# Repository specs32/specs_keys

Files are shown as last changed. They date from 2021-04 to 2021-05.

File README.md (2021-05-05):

# specs_keys - REV 1 (confirmed working, typing on it now :D)

### TKL ISO keyboard based on an g80-3000HAD running QMK

15 Years ago I found 2 g80-3000 HAD Keyboards in the trash, one broke lately so I designed a PCB to mount these sweet sweet Cherry MX black switches on it.

The base plate is the acryl plate from an old TFT Monitor cut to size and sanded. (roughly)
Between PCB and baseplate is some foamy stuff for dampening.

So, except the pcb and the mcu and a couple smd parts this thing is completly salvaged from trash.

Overall cost per board with parts (except switches) : 18 €

(8 € per PCB and 10 € for SMD parts, rest is salvaged, so this is probably the cheapest build out there)

Features  :
  - ATMega 32U4 @ 8 MHz (why the crystal ... such a waste, sigh)
  - USB-C jack **with FUSE and full ESD protection** (gnd vcc d+ d-)
  - MOSFET controlled bottom backlighting pads for 14 LEDs with resistors plus 2 extra 2mm connectors for lantern style lightning
  - Scroll and caps indicators (active low atm.. I kinda like it)
  - SPI interface and reset
  - 340mA overall power consumption with full lights (I put in UV / pink LEDs and 14 Ω Resistors)

the QMK layout and config can be found here :  https://github.com/specs32/specs_keys/tree/main/specskeys

I hex the MCU with avrdude from cli after QMK compile, somehow I had trouble with bootloaders all my life ^^ (also safer this way .. I guess;))

> qmk_firmware [master]× » avrdude -c usbasp -p m32u4 -B10 -U lfuse:w:0xD2:m -U hfuse:w:0x98:m -U efuse:w:0xFF:m

> qmk_firmware [master]× » avrdude -c usbasp -pm32u4 -B10 -Uflash:w:.build/specskeys_default.hex                

designed with kicad nightly Version: (5.99.0-10004-g132ec37b56), release build
and some gimp

credits :

- evyd13 and ebastler (to modify the g80-3003 design was my initial attempt but I did build the PCB from scratch then)
- the designers of evil80 (whoever that might be, couldn't find any infos on that) I used some of their qmk layout information as info for mine

License on the KiCAD Design files : ♥ CC-BY-SA-4.0

All other parts of this build inherit their Licenses from their origin.

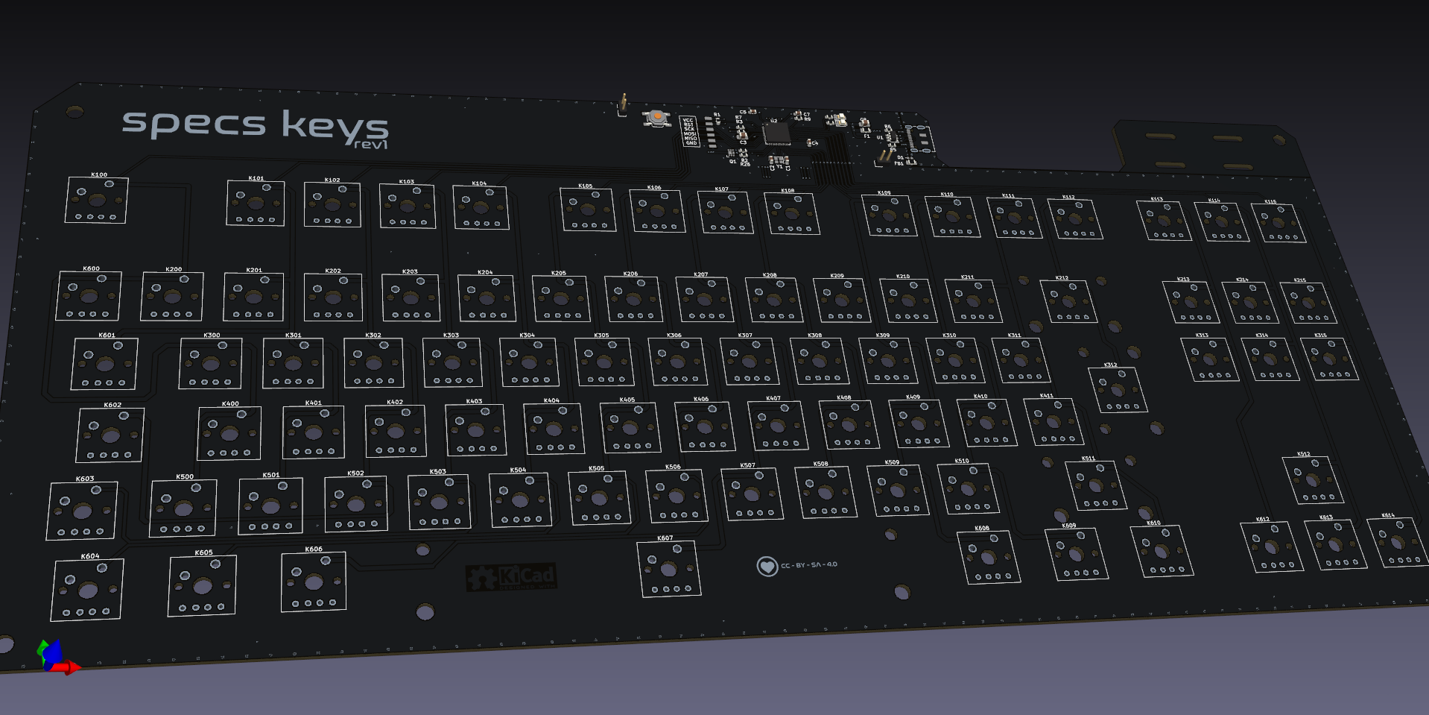
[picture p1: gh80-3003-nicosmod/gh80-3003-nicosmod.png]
3d-VIEW


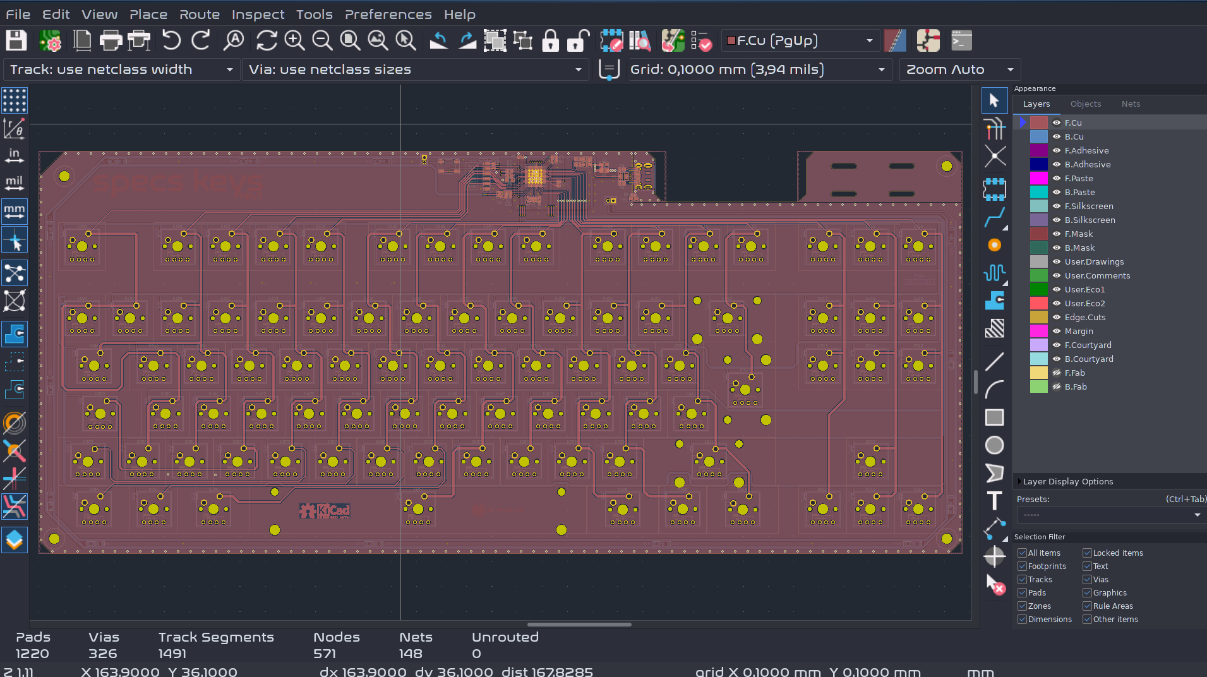
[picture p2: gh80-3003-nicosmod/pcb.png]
PCB
 

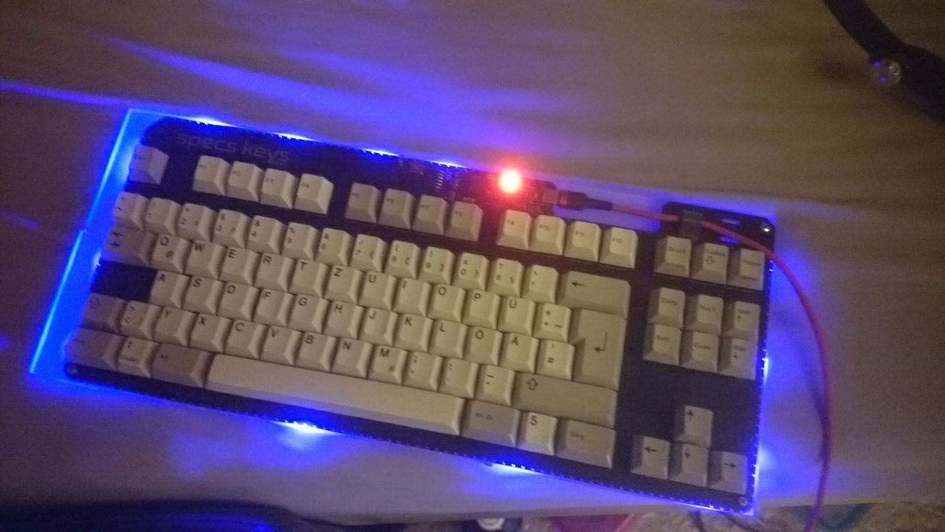
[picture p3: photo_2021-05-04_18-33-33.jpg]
FOTO1


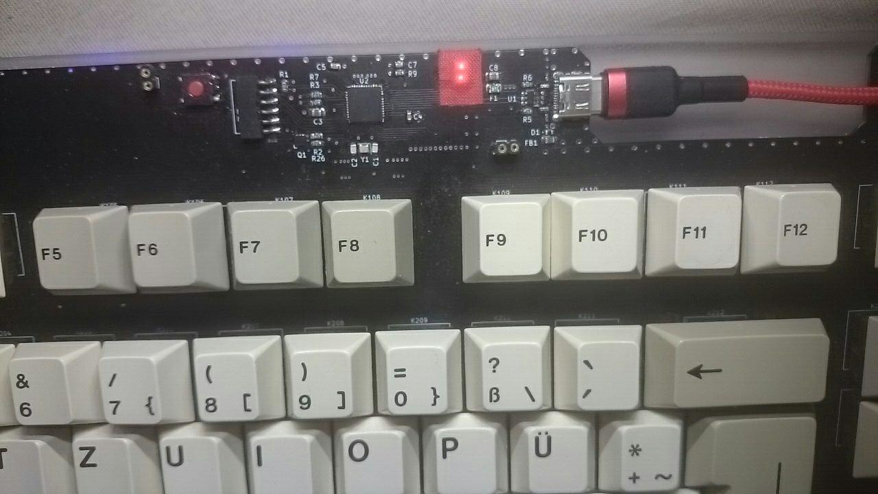
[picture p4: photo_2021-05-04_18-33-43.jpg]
FOTO2


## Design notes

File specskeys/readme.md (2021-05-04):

# specskeys

specskeys

*A short description of the keyboard/project*

* Keyboard Maintainer: [specs32](https://github.com/yourusername)
* Hardware Supported: *The PCBs, controllers supported*
* Hardware Availability: *Links to where you can find this hardware*

Make example for this keyboard (after setting up your build environment):

    make specskeys:default

Flashing example for this keyboard:

    make specskeys:default:flash

See the [build environment setup](https://docs.qmk.fm/#/getting_started_build_tools) and the [make instructions](https://docs.qmk.fm/#/getting_started_make_guide) for more information. Brand new to QMK? Start with our [Complete Newbs Guide](https://docs.qmk.fm/#/newbs).

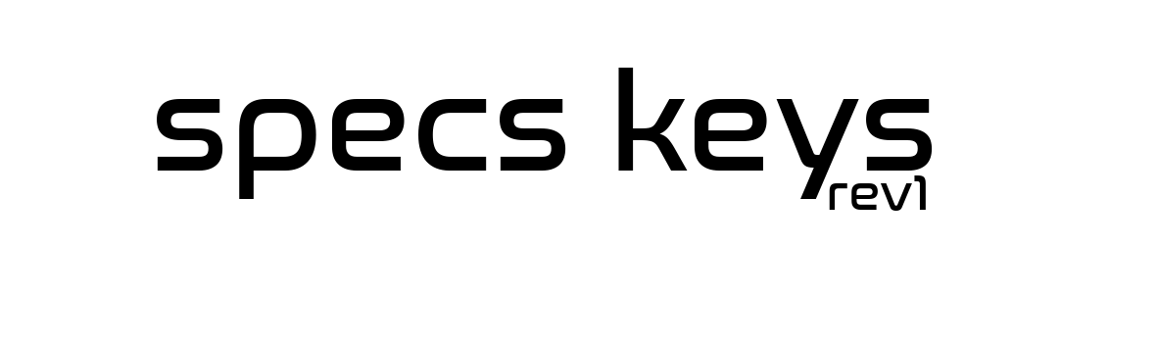
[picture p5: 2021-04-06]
gh80-3003-nicosmod/specskeys_rev1.png

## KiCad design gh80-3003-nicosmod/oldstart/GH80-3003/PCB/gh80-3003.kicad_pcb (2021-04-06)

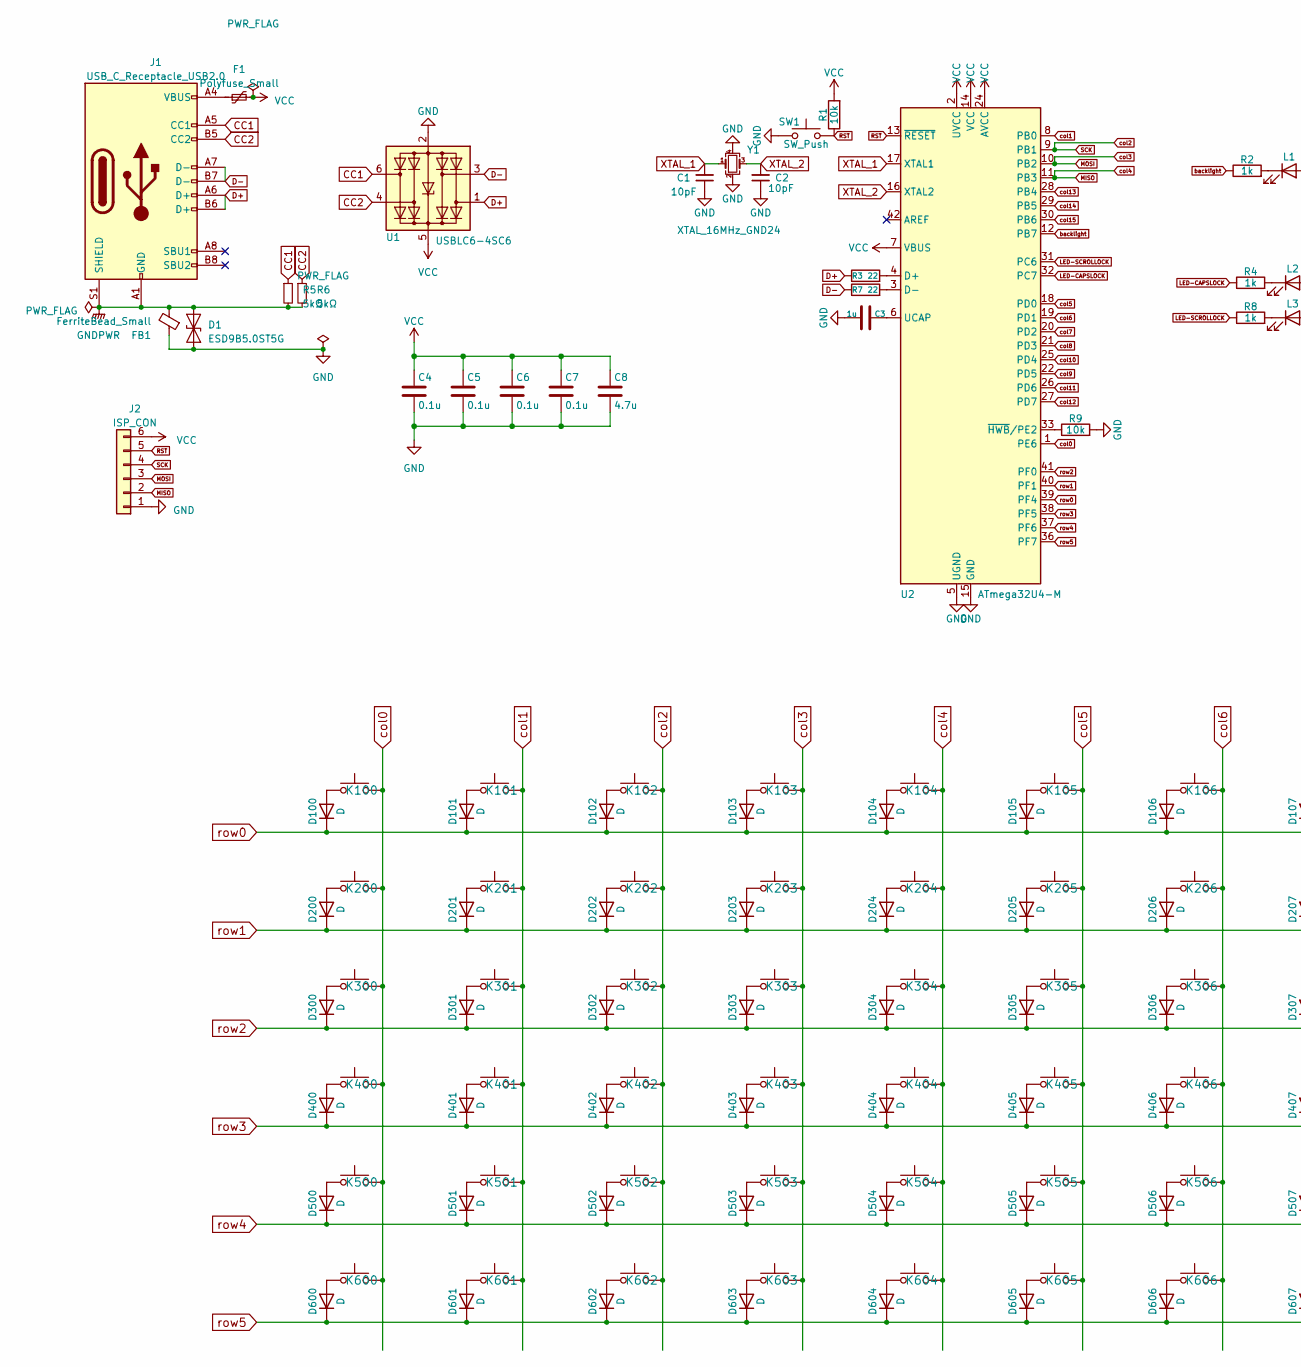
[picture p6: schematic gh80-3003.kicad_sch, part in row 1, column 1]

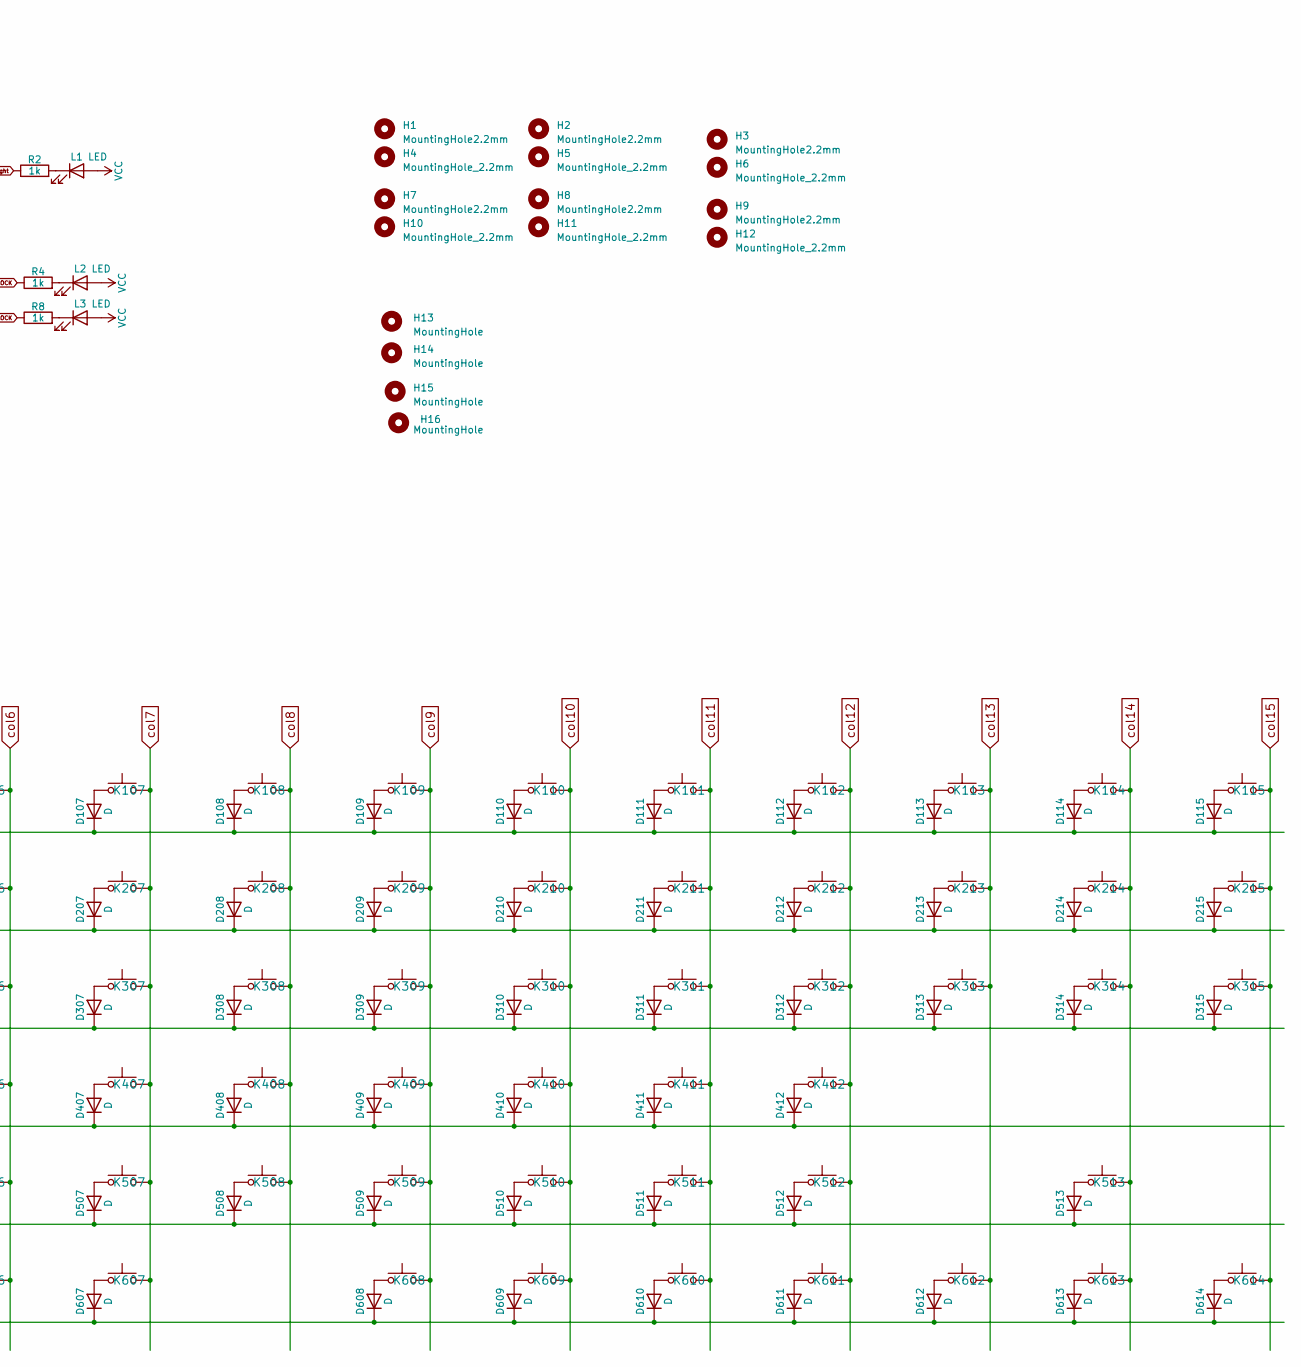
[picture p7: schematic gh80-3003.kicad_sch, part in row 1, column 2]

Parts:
C1, C2: 10pF; C_0603_1608Metric_Pad1.08x0.95mm_HandSolder
C3: 1u; C_0805_2012Metric_Pad1.18x1.45mm_HandSolder
C4, C5, C6, C7: 0.1u; C_0603_1608Metric
C8: 4.7u; C_0805_2012Metric_Pad1.18x1.45mm_HandSolder
D1: ESD9B5.0ST5G; D_0402_1005Metric_Pad0.77x0.64mm_HandSolder
D100, D101, D102, D103, D104, D105, D106, D107, D108, D109, D110, D111, D112, D113, D114, D115, D200, D201, D202, D203, D204, D205, D206, D207, D208, D209, D210, D211, D212, D213, D214, D215, D300, D301, D302, D303, D304, D305, D306, D307, D308, D309, D310, D311, D312, D313, D314, D315, D400, D401, D402, D403, D404, D405, D406, D407, D408, D409, D410, D411, D412, D500, D501, D502, D503, D504, D505, D506, D507, D508, D509, D510, D511, D512, D513, D600, D601, D602, D603, D604, D605, D606, D607, D608, D609, D610, D611, D612, D613, D614: D; D_0402_1005Metric_Pad0.77x0.64mm_HandSolder
F1: Polyfuse_Small; R_0805_2012Metric_Pad1.20x1.40mm_HandSolder
FB1: FerriteBead_Small; R_0805_2012Metric_Pad1.20x1.40mm_HandSolder
H1, H2, H3, H7, H8, H9: MountingHole2.2mm; MountingHole_2.2mm_M2
H4, H5, H6, H10, H11, H12: MountingHole_2.2mm; MountingHole_2.2mm_M2
H13, H14, H15, H16: MountingHole; MountingHole_5.3mm_M5_ISO14580
J1: USB_C_Receptacle_USB2.0; USB_C_Receptacle_JAE_DX07S016JA1R1500
J2: ISP_CON; Conn_01x06_SMD_2mm
K100, K101, K102, K103, K104, K105, K106, K107, K108, K109, K110, K111, K112, K113, K114, K115, K200, K201, K202, K203, K204, K205, K206, K207, K208, K209, K210, K211, K212, K213, K214, K215, K300, K301, K302, K303, K304, K305, K306, K307, K308, K309, K310, K311, K312, K313, K314, K315, K400, K401, K402, K403, K404, K405, K406, K407, K408, K409, K410, K411, K412, K500, K501, K502, K503, K504, K505, K506, K507, K508, K509, K510, K511, K512, K513, K600, K605, K606, K607, K608, K609, K610, K611, K612, K613, K614: SW_Push; SW_Cherry_MX_1.00u_PCB
K601, K603: SW_Push; SW_Cherry_MX_1.50u_PCB
K602: SW_Push; SW_Cherry_MX_2.00u_PCB
K604: SW_Push; SW_Cherry_MX_1.75u_PCB
L1, L2, L3: LED; LED_0805_2012Metric_Pad1.15x1.40mm_HandSolder
R1, R9: 10k; R_0603_1608Metric
R2, R4, R8: 1k; R_0603_1608Metric
R3, R7: 22; R_0603_1608Metric
R5, R6: 5kΩ; R_0603_1608Metric
SW1: SW_Push; SW_SPST_TL3342
U1: USBLC6-4SC6; SOT-23-6
U2: ATmega32U4-M; QFN-44-1EP_7x7mm_P0.5mm_EP5.2x5.2mm
Y1: XTAL_16MHz_GND24; Crystal_SMD_2016-4Pin_2.0x1.6mm

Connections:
CC1: J1.A5 (CC1), R5.1, U1.6 (I/O4)
CC2: J1.B5 (CC2), R6.1, U1.4 (I/O3)
D+: J1.A6 (D+), J1.B6 (D+), R3.1, U1.1 (I/O1)
D-: J1.A7 (D-), J1.B7 (D-), R7.1, U1.3 (I/O2)
GND: C1.1, C2.1, C3.2, C4.2, C5.2, C6.2, C7.2, C8.2, D1.1 (A1), FB1.1, J2.1, R9.2, SW1.1, U1.2 (GND), U2.5 (UGND), U2.15 (GND), U2.23 (GND), U2.35 (GND), U2.43 (GND), U2.45 (GND), Y1.2, Y1.4
GNDPWR: D1.2 (A2), FB1.2, J1.A1 (GND), J1.A12 (GND), J1.B1 (GND), J1.B12 (GND), J1.S1 (SHIELD), R5.2, R6.2
LED-CAPSLOCK: R4.1, U2.32 (PC7)
LED-SCROLLOCK: R8.1, U2.31 (PC6)
MISO: J2.2, K104.1, K204.1, K304.1, K404.1, K504.1, K604.1, U2.11 (PB3)
MOSI: J2.3, K103.1, K203.1, K303.1, K403.1, K503.1, K603.1, U2.10 (PB2)
unnamed: C3.1, U2.6 (UCAP)
unnamed: D100.2 (A), K100.2
unnamed: D101.2 (A), K101.2
unnamed: D102.2 (A), K102.2
unnamed: D103.2 (A), K103.2
unnamed: D104.2 (A), K104.2
unnamed: D105.2 (A), K105.2
unnamed: D106.2 (A), K106.2
unnamed: D107.2 (A), K107.2
unnamed: D108.2 (A), K108.2
unnamed: D109.2 (A), K109.2
unnamed: D110.2 (A), K110.2
unnamed: D111.2 (A), K111.2
unnamed: D112.2 (A), K112.2
unnamed: D113.2 (A), K113.2
unnamed: D114.2 (A), K114.2
unnamed: D115.2 (A), K115.2
unnamed: D200.2 (A), K200.2
unnamed: D201.2 (A), K201.2
unnamed: D203.2 (A), K203.2
unnamed: D205.2 (A), K205.2
unnamed: D206.2 (A), K206.2
unnamed: D207.2 (A), K207.2
unnamed: D209.2 (A), K209.2
unnamed: D210.2 (A), K210.2
unnamed: D211.2 (A), K211.2
unnamed: D212.2 (A), K212.2
unnamed: D213.2 (A), K213.2
unnamed: D214.2 (A), K214.2
unnamed: D215.2 (A), K215.2
unnamed: D300.2 (A), K300.2
unnamed: D301.2 (A), K301.2
unnamed: D302.2 (A), K302.2
unnamed: D303.2 (A), K303.2
unnamed: D304.2 (A), K304.2
unnamed: D305.2 (A), K305.2
unnamed: D306.2 (A), K306.2
unnamed: D307.2 (A), K307.2
unnamed: D308.2 (A), K308.2
unnamed: D309.2 (A), K309.2
unnamed: D310.2 (A), K310.2
unnamed: D311.2 (A), K311.2
unnamed: D312.2 (A), K312.2
unnamed: D313.2 (A), K313.2
unnamed: D314.2 (A), K314.2
unnamed: D315.2 (A), K315.2
unnamed: D400.2 (A), K400.2
unnamed: D401.2 (A), K401.2
unnamed: D402.2 (A), K402.2
unnamed: D403.2 (A), K403.2
unnamed: D404.2 (A), K404.2
unnamed: D405.2 (A), K405.2
unnamed: D406.2 (A), K406.2
unnamed: D407.2 (A), K407.2
unnamed: D408.2 (A), K408.2
unnamed: D409.2 (A), K409.2
unnamed: D410.2 (A), K410.2
unnamed: D411.2 (A), K411.2
unnamed: D412.2 (A), K412.2
unnamed: D500.2 (A), K500.2
unnamed: D501.2 (A), K501.2
unnamed: D502.2 (A), K502.2
unnamed: D503.2 (A), K503.2
unnamed: D504.2 (A), K504.2
unnamed: D505.2 (A), K505.2
unnamed: D506.2 (A), K506.2
unnamed: D507.2 (A), K507.2
unnamed: D508.2 (A), K508.2
unnamed: D509.2 (A), K509.2
unnamed: D510.2 (A), K510.2
unnamed: D511.2 (A), K511.2
unnamed: D512.2 (A), K512.2
unnamed: D513.2 (A), K513.2
unnamed: D600.2 (A), K600.2
unnamed: D601.2 (A), K601.2
unnamed: D602.2 (A), K602.2
unnamed: D603.2 (A), K603.2
unnamed: D604.2 (A), K604.2
unnamed: D605.2 (A), K605.2
unnamed: D606.2 (A), K606.2
unnamed: D607.2 (A), K607.2
unnamed: D608.2 (A), K608.2
unnamed: D609.2 (A), K609.2
unnamed: D610.2 (A), K610.2
unnamed: D611.2 (A), K611.2
unnamed: D612.2 (A), K612.2
unnamed: D613.2 (A), K613.2
unnamed: D614.2 (A), K614.2
unnamed: F1.1, J1.A4 (VBUS), J1.A9 (VBUS), J1.B4 (VBUS), J1.B9 (VBUS)
unnamed: D202.2 (A), K202.2
unnamed: D204.2 (A), K204.2
unnamed: D208.2 (A), K208.2
unnamed: L1.1 (K), R2.2
unnamed: L2.1 (K), R4.2
unnamed: L3.1 (K), R8.2
unnamed: R3.2, U2.4 (D+)
unnamed: R7.2, U2.3 (D-)
unnamed: R9.1, U2.33 (~HWB~/PE2)
RST: J2.5, R1.1, SW1.2, U2.13 (~RESET)
SCK: J2.4, K102.1, K202.1, K302.1, K402.1, K502.1, K602.1, U2.9 (PB1)
VCC: C4.1, C5.1, C6.1, C7.1, C8.1, F1.2, J2.6, L1.2 (A), L2.2 (A), L3.2 (A), R1.2, U1.5 (VBUS), U2.2 (UVCC), U2.7 (VBUS), U2.14 (VCC), U2.24 (AVCC), U2.34 (VCC), U2.44 (AVCC)
XTAL_1: C1.2, U2.17 (XTAL1), Y1.1
XTAL_2: C2.2, U2.16 (XTAL2), Y1.3
backlight: R2.1, U2.12 (PB7)
col0: K100.1, K200.1, K300.1, K400.1, K500.1, K600.1, U2.1 (PE6)
col1: K101.1, K201.1, K301.1, K401.1, K501.1, K601.1, U2.8 (PB0)
col5: K105.1, K205.1, K305.1, K405.1, K505.1, K605.1, U2.18 (PD0)
col6: K106.1, K206.1, K306.1, K406.1, K506.1, K606.1, U2.19 (PD1)
col7: K107.1, K207.1, K307.1, K407.1, K507.1, K607.1, U2.20 (PD2)
col8: K108.1, K208.1, K308.1, K408.1, K508.1, U2.21 (PD3)
col9: K109.1, K209.1, K309.1, K409.1, K509.1, K608.1, U2.22 (PD5)
col10: K110.1, K210.1, K310.1, K410.1, K510.1, K609.1, U2.25 (PD4)
col11: K111.1, K211.1, K311.1, K411.1, K511.1, K610.1, U2.26 (PD6)
col12: K112.1, K212.1, K312.1, K412.1, K512.1, K611.1, U2.27 (PD7)
col13: K113.1, K213.1, K313.1, K612.1, U2.28 (PB4)
col14: K114.1, K214.1, K314.1, K513.1, K613.1, U2.29 (PB5)
col15: K115.1, K215.1, K315.1, K614.1, U2.30 (PB6)
row0: D100.1 (K), D101.1 (K), D102.1 (K), D103.1 (K), D104.1 (K), D105.1 (K), D106.1 (K), D107.1 (K), D108.1 (K), D109.1 (K), D110.1 (K), D111.1 (K), D112.1 (K), D113.1 (K), D114.1 (K), D115.1 (K), U2.39 (PF4)
row1: D200.1 (K), D201.1 (K), D202.1 (K), D203.1 (K), D204.1 (K), D205.1 (K), D206.1 (K), D207.1 (K), D208.1 (K), D209.1 (K), D210.1 (K), D211.1 (K), D212.1 (K), D213.1 (K), D214.1 (K), D215.1 (K), U2.40 (PF1)
row2: D300.1 (K), D301.1 (K), D302.1 (K), D303.1 (K), D304.1 (K), D305.1 (K), D306.1 (K), D307.1 (K), D308.1 (K), D309.1 (K), D310.1 (K), D311.1 (K), D312.1 (K), D313.1 (K), D314.1 (K), D315.1 (K), U2.41 (PF0)
row3: D400.1 (K), D401.1 (K), D402.1 (K), D403.1 (K), D404.1 (K), D405.1 (K), D406.1 (K), D407.1 (K), D408.1 (K), D409.1 (K), D410.1 (K), D411.1 (K), D412.1 (K), U2.38 (PF5)
row4: D500.1 (K), D501.1 (K), D502.1 (K), D503.1 (K), D504.1 (K), D505.1 (K), D506.1 (K), D507.1 (K), D508.1 (K), D509.1 (K), D510.1 (K), D511.1 (K), D512.1 (K), D513.1 (K), U2.37 (PF6)
row5: D600.1 (K), D601.1 (K), D602.1 (K), D603.1 (K), D604.1 (K), D605.1 (K), D606.1 (K), D607.1 (K), D608.1 (K), D609.1 (K), D610.1 (K), D611.1 (K), D612.1 (K), D613.1 (K), D614.1 (K), U2.36 (PF7)

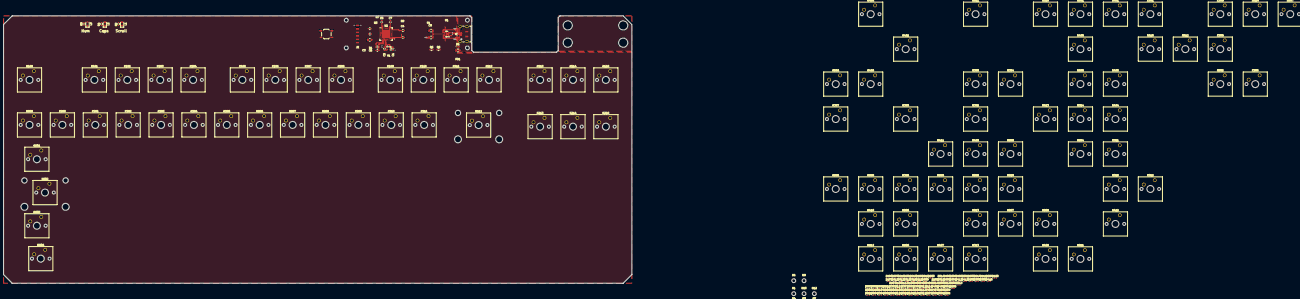
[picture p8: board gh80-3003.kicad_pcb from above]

Board: 4 copper layers, 363.0 x 154.5 mm, 225 parts (0 on the bottom side), 133 nets.
